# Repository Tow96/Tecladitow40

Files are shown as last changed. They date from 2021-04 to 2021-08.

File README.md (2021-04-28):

# Tecladitow-40





The Tecladitow40 is a simple 40% handwired ortholinear keyboard which utilizes 
[QMK](https://github.com/qmk/qmk_firmware) to communicate with any USB capable 
device. The Tecladitow40 is based on a Teensy2.0 microcontroller.

## Repository structure
The repository is divided in two subfolders, each containing a different part of 
the project. Further documentation can be found inside these folders.

1. [**Assembly**](/Assembly) - This folder contains the files that make up the 
physical keyboard. They are available in .SLDPRT and .STL formats.

2. [**Firmware**](/Firmware) - This folder contains the Hex file used to flash the
keyboard as well as a simple Test program to check the functionality of the keys.

## Future improvements
The specific improvements are separated by category inside the documentation for each folder.

- [ ] **Make rev1:** This revision will change the microcontroller to a pure 
ATmega32u4 and have a pcb.

## Credits
- Jose Tow [[@Tow96](https://github.com/Tow96)]

## License
This project is licensed under [GNU GPL-3.0](/LICENSE) as I believe in open source 
projects.

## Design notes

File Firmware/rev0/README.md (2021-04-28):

# Firmware
The tecladitow40 utilizes the QMK firmware. in this repository only the code to test the switches and the compiled hex file for the keyboard can be found.

The uncompiled version of the firmware can be found on this 
[forked repository](https://github.com/Tow96-forks/qmk_firmware).

## Future improvements
- [ ] Make rev1

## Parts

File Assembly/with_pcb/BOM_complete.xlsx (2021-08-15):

Item # | Part | Value | Qty | Description | Package | Type | LCSC-PART | Units per Lot | Lot Price (USD) | Total (1 brd) | Total (2 brd) | Total (3 brd) | Total (4 brd) | Total (5 brd) | Link
1 | C1-C47 | 0.1uF | 47 | Capacitor | 0402 | SMD | C392963 | 100 | 0.82 | 0.82 | 0.82 | 1.64 | 1.64 | 2.46 | https://es.aliexpress.com/item/32965092877.html
2 | C48, C51-C54 | 1uF | 5 | Capacitor | 0402 | SMD | C107372 | 100 | 0.82 | 0.82 | 0.82 | 0.82 | 0.82 | 0.82 | https://es.aliexpress.com/item/32965092877.html
3 | C49-C50 | 30pF | 2 | Capacitor | 0402 | SMD | C107004 | 100 | 0.82 | 0.82 | 0.82 | 0.82 | 0.82 | 0.82 | https://es.aliexpress.com/item/32965092877.html
4 | CR1-CR47 |  | 47 | SK6812Mini-E LED | - | SMD |  | 100 | 17.35 | 12.59 | 17.35 | 34.70 | 34.70 | 42.99 | https://es.aliexpress.com/item/4000475685852.html
5 | D1-D47 | 4148 | 47 | Diode | MINI-MELF | SMD | C402260 | 100 | 0.70 | 0.70 | 0.70 | 1.40 | 1.40 | 2.10 | https://es.aliexpress.com/item/1005002345510929.html
6 | G1 | 16MHz | 1 | 16MHz Crystal | SMD3225-4P | SMD | C12668 | 10 | 1.37 | 1.37 | 1.37 | 1.37 | 1.37 | 1.37 | https://es.aliexpress.com/item/1005002345332969.html
7 | J1 |  | 1 | Female USB-C | - | SMD | C393939 | 5 | 0.68 | 0.68 | 0.68 | 0.68 | 0.68 | 0.68 | https://lcsc.com/product-detail/USB-Connectors_SHOU-HAN-TYPE-C16PIN_C393939.html
8 | R1-R2 | 5.1K | 2 | Resistor | 0402 | SMD | C325521 | 100 | 0.64 | 0.64 | 0.64 | 0.64 | 0.64 | 0.64 | https://es.aliexpress.com/item/1005001793275257.html
9 | R3-R4 | 22 | 2 | Resistor | 0402 | SMD | C163821 | 100 | 0.64 | 0.64 | 0.64 | 0.64 | 0.64 | 0.64 | https://es.aliexpress.com/item/1005001793275257.html
10 | R5 | 10K | 1 | Resistor | 0402 | SMD | C140214 | 100 | 0.64 | 0.64 | 0.64 | 0.64 | 0.64 | 0.64 | https://es.aliexpress.com/item/1005001793275257.html
11 | R6 | 300 | 1 | Resistor | 0402 | SMD | C911734 | 100 | 0.64 | 0.64 | 0.64 | 0.64 | 0.64 | 0.64 | https://es.aliexpress.com/item/1005001793275257.html
12 | S1-S47 |  | 47 | Cherry MX Switch | CherryMX | thru-hole
13 | S48 |  | 1 | Tactile Switch | SMD,3*4 | SMD | C455280 | 100 | 1.76 | 1.76 | 1.76 | 1.76 | 1.76 | 1.76 | https://es.aliexpress.com/item/4001107238344.html
14 | U$1 |  | 1 | JST SR Female connector | - | SMD | C160407 | 10 | 2.04 | 2.04 | 2.04 | 2.04 | 2.04 | 2.04 | https://lcsc.com/product-detail/Wire-To-Board-Wire-To-Wire-Connector_JST-Sales-America-SM08B-SRSS-TB-LF-SN_C160407.html
15 | U1 |  | 1 | ATmega32u4MU | QFN-44_7x7x05P | SMD | C45874 | 5 | 29.10 | 29.10 | 29.10 | 29.10 | 29.10 | 29.10 | https://es.aliexpress.com/item/1005002509013804.html
16 | - | M2.5 | 5 | Screws | - | - | - | -
17 | - |  | 1 | 48 Ortholinear keycaps
 |  |  |  |  | Prices without discount nor shipment |  |  |  | SubTotal | 53.26 | 58.02 | 76.89 | 76.89 | 86.70
 |  |  |  |  |  |  |  |  | SubTotal per board | 53.2600 | 29.0100 | 25.6300 | 19.2225 | 17.3400
18 | - | - | 1 | PCB @ JLC | - | PCB | - | 5 | 60.5 | 60.50 | 60.50 | 60.50 | 60.50 | 60.50
 |  |  |  |  |  |  |  |  | Total | 113.76 | 118.52 | 137.39 | 137.39 | 147.20
 |  |  |  |  |  |  |  |  | Total per board | 113.7600 | 59.2600 | 45.7967 | 34.3475 | 29.4400

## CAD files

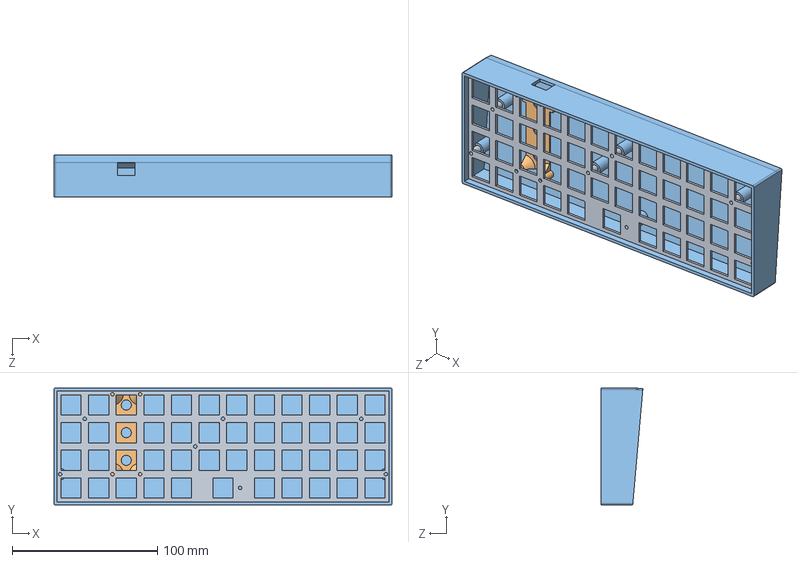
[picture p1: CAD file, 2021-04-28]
Assembly/hand-soldered/Keyboard.SLDASM
233.0 x 80.6 x 28.8 mm
01-Plate
02-TeensyBase
03-Body

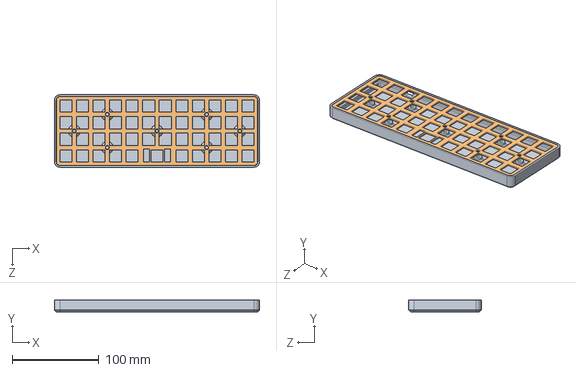
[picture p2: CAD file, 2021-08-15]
Assembly/with_pcb/Parts/_src/Assembly.SLDASM
235.8 x 13.5 x 83.4 mm
Plate

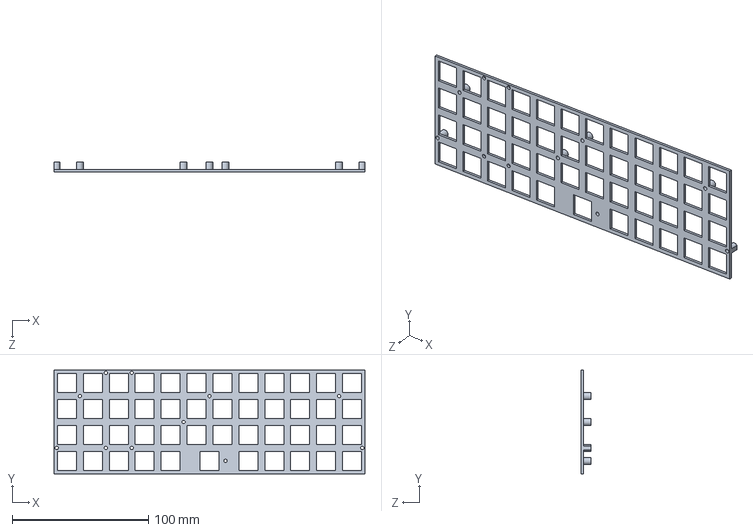
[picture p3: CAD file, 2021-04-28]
Assembly/hand-soldered/Parts/01-Plate.SLDPRT
228.6 x 76.2 x 7.20 mm

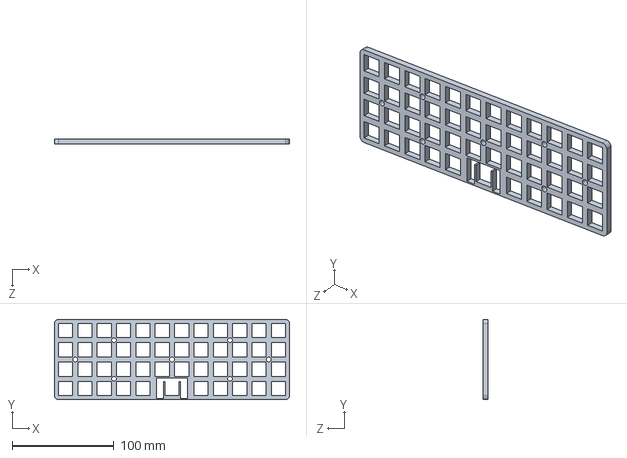
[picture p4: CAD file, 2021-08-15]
Assembly/with_pcb/Parts/_src/Plate.SLDPRT
231.4 x 79.0 x 5.00 mm

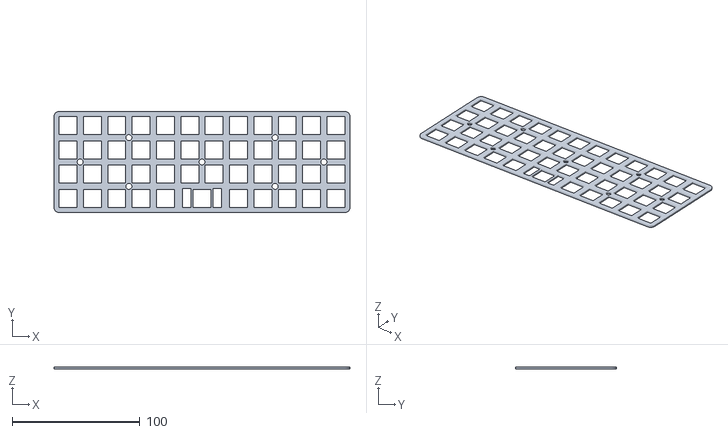
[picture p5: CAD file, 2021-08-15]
Assembly/with_pcb/Parts/STL/Plate_1.5mm.STL
231.4 x 79.0 x 1.50

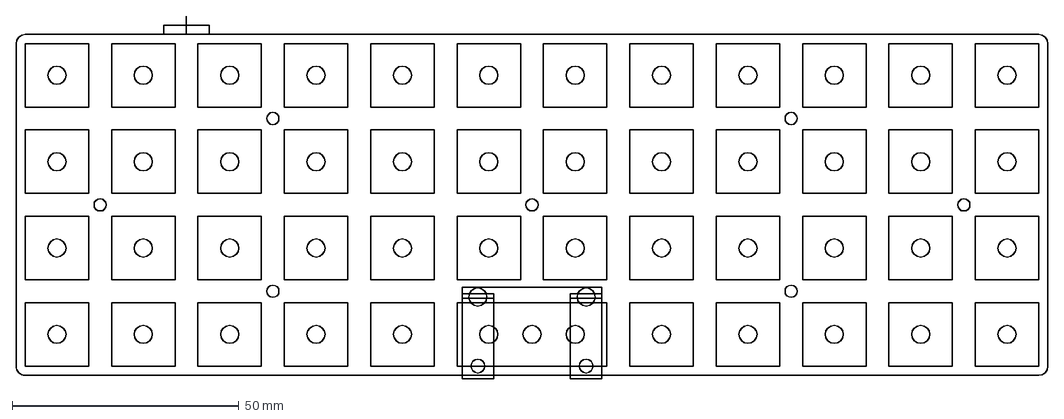
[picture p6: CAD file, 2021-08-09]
Assembly/with_pcb/reference_plate.dxf
227.5 x 79.9 mm

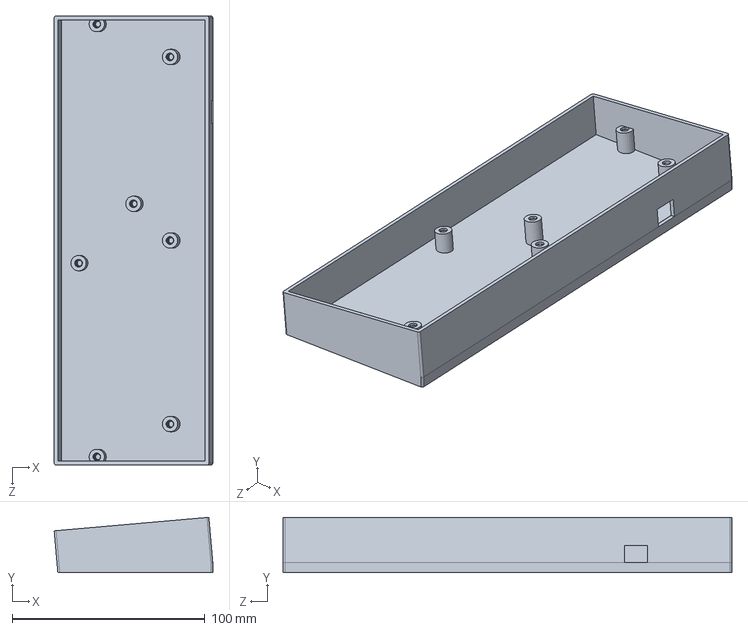
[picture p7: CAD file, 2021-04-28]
Assembly/hand-soldered/Parts/03-Body.SLDPRT
82.4 x 28.7 x 233.0 mm

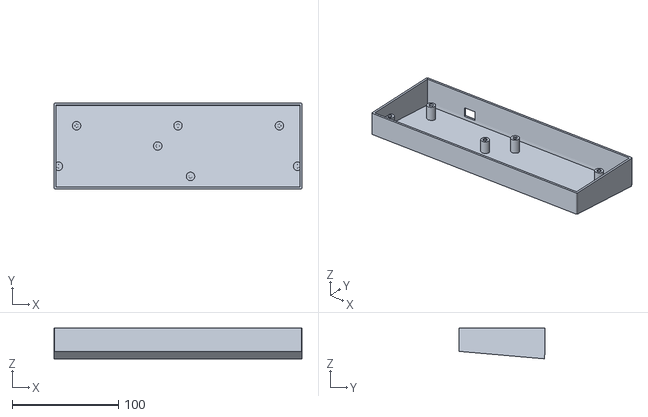
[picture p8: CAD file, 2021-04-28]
Assembly/hand-soldered/STL/Keyboard - 03-Body-1.STL
233.0 x 80.6 x 28.8

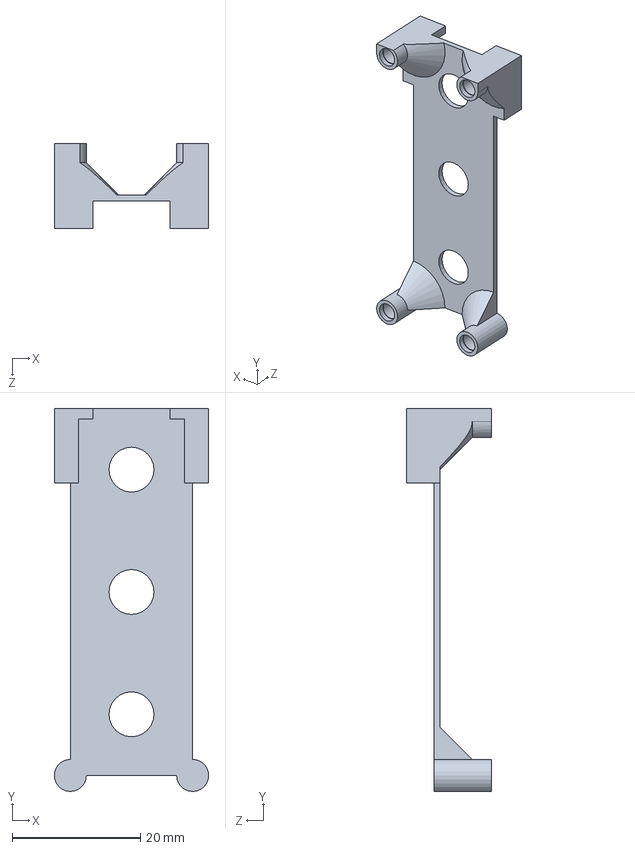
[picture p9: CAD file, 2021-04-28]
Assembly/hand-soldered/Parts/02-TeensyBase.SLDPRT
24.0 x 59.7 x 13.2 mm

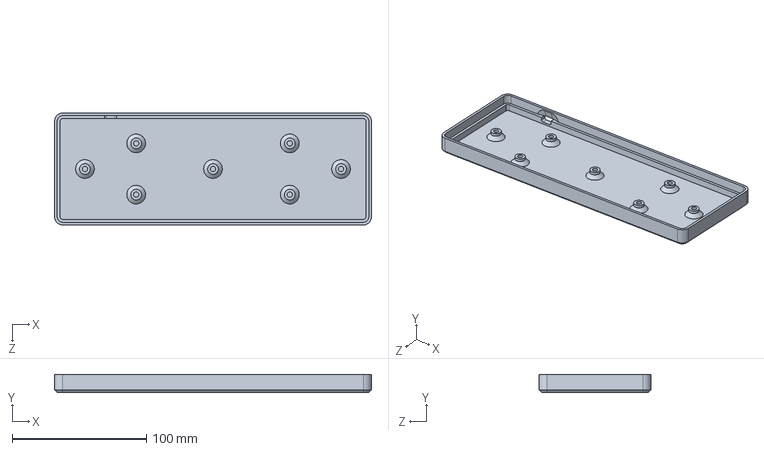
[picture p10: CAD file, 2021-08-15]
Assembly/with_pcb/Parts/_src/Body.SLDPRT
235.8 x 13.5 x 83.4 mm

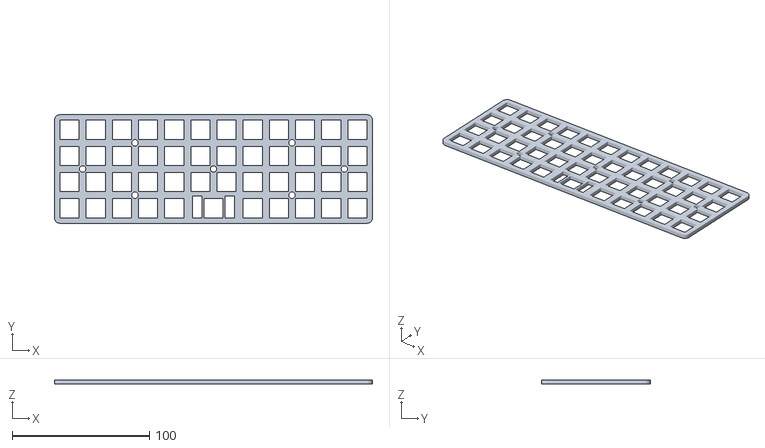
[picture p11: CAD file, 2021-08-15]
Assembly/with_pcb/Parts/STL/Plate_3.0mm.STL
231.4 x 79.0 x 3.00

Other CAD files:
Assembly/hand-soldered/STL/Keyboard - 01-Plate-1.STL
Assembly/with_pcb/Parts/STL/Plate_5.0mm.STL
Assembly/hand-soldered/STL/Keyboard - 02-TeensyBase-1.STL
Assembly/with_pcb/Parts/STL/Body.STL

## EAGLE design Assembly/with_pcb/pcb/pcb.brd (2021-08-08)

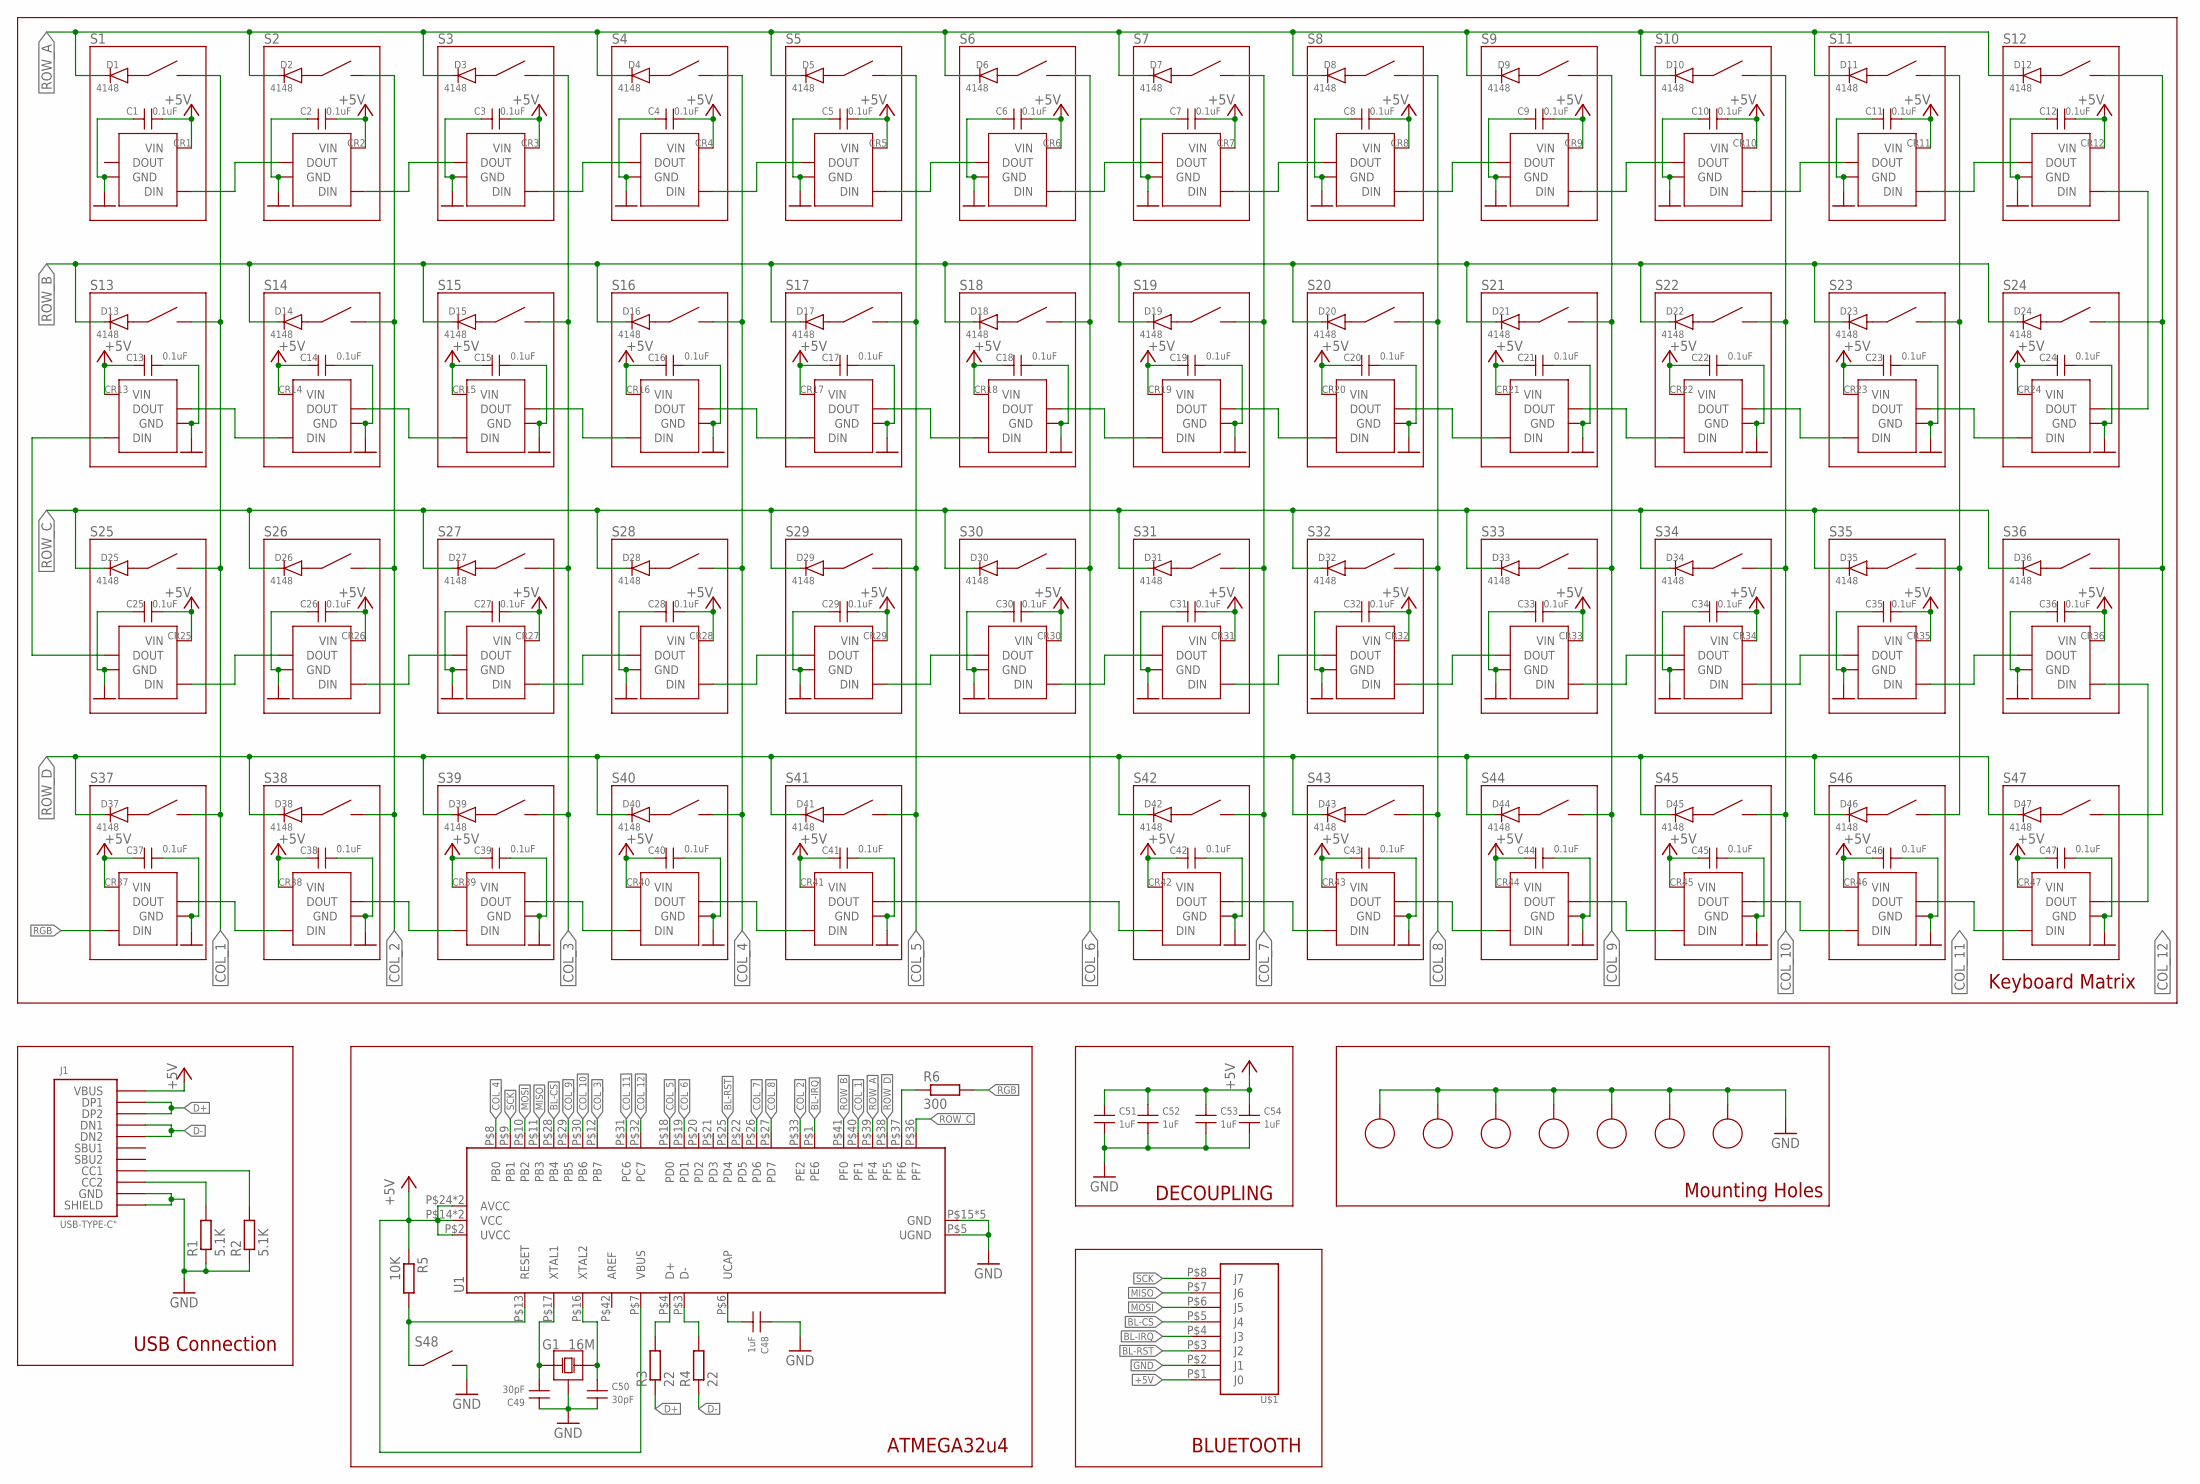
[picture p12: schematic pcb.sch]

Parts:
C1, C2, C3, C4, C5, C6, C7, C8, C9, C10, C11, C12, C13, C14, C15, C16, C17, C18, C19, C20, C21, C22, C23, C24, C25, C26, C27, C28, C29, C30, C31, C32, C33, C34, C35, C36, C37, C38, C39, C40, C41, C42, C43, C44, C45, C46, C47: 0.1uF; C0402
C48, C51, C52, C53, C54: 1uF; C0402
C49, C50: 30pF; C0402
CR1, CR2, CR3, CR4, CR5, CR6, CR7, CR8, CR9, CR10, CR11, CR12, CR13, CR14, CR15, CR16, CR17, CR18, CR19, CR20, CR21, CR22, CR23, CR24, CR25, CR26, CR27, CR28, CR29, CR30, CR31, CR32, CR33, CR34, CR35, CR36, CR37, CR38, CR39, CR40, CR41, CR42, CR43, CR44, CR45, CR46, CR47: SK6812MINI-E
D1, D2, D3, D4, D5, D6, D7, D8, D9, D10, D11, D12, D13, D14, D15, D16, D17, D18, D19, D20, D21, D22, D23, D24, D25, D26, D27, D28, D29, D30, D31, D32, D33, D34, D35, D36, D37, D38, D39, D40, D41, D42, D43, D44, D45, D46, D47: 4148; MINI_MELF
G1: 16M; SMD3225-4P
J1: USB-TYPE-C"; USB-C-SMD_TYPE-C16PIN
R1, R2: 5.1K; R0402
R3, R4: 22; R0402
R5: 10K; R0402
R6: 300; R0402
S1, S2, S3, S4, S5, S6, S7, S8, S9, S10, S11, S12, S13, S14, S15, S16, S17, S18, S19, S20, S21, S22, S23, S24, S25, S26, S27, S28, S29, S30, S31, S32, S33, S34, S35, S36, S37, S38, S39, S40, S41, S42, S43, S44, S45, S46, S47: MX_SWITCH
S48: SWITCH-SMD,3*4; SMD,3X4X2.0MM
U1: ATMEGA32U4-MUR; QFN-44_7X7X05P
U2, U3, U4, U5, U6, U7, U8: M2.5-HOLE; M2.5
U$1: JST-8PIN-SR; JST-SR-8PIN

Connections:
+5V: C1.P$2, C2.P$2, C3.P$2, C4.P$2, C5.P$2, C6.P$2, C7.P$2, C8.P$2, C9.P$2, C10.P$2, C11.P$2, C12.P$2, C13.P$1, C14.P$1, C15.P$1, C16.P$1, C17.P$1, C18.P$1, C19.P$1, C20.P$1, C21.P$1, C22.P$1, C23.P$1, C24.P$1, C25.P$2, C26.P$2, C27.P$2, C28.P$2, C29.P$2, C30.P$2, C31.P$2, C32.P$2, C33.P$2, C34.P$2, C35.P$2, C36.P$2, C37.P$1, C38.P$1, C39.P$1, C40.P$1, C41.P$1, C42.P$1, C43.P$1, C44.P$1, C45.P$1, C46.P$1, C47.P$1, C51.P$1, C52.P$1, C53.P$1, C54.P$1, CR1.P$1 (VIN), CR2.P$1 (VIN), CR3.P$1 (VIN), CR4.P$1 (VIN), CR5.P$1 (VIN), CR6.P$1 (VIN), CR7.P$1 (VIN), CR8.P$1 (VIN), CR9.P$1 (VIN), CR10.P$1 (VIN), CR11.P$1 (VIN), CR12.P$1 (VIN), CR13.P$1 (VIN), CR14.P$1 (VIN), CR15.P$1 (VIN), CR16.P$1 (VIN), CR17.P$1 (VIN), CR18.P$1 (VIN), CR19.P$1 (VIN), CR20.P$1 (VIN), CR21.P$1 (VIN), CR22.P$1 (VIN), CR23.P$1 (VIN), CR24.P$1 (VIN), CR25.P$1 (VIN), CR26.P$1 (VIN), CR27.P$1 (VIN), CR28.P$1 (VIN), CR29.P$1 (VIN), CR30.P$1 (VIN), CR31.P$1 (VIN), CR32.P$1 (VIN), CR33.P$1 (VIN), CR34.P$1 (VIN), CR35.P$1 (VIN), CR36.P$1 (VIN), CR37.P$1 (VIN), CR38.P$1 (VIN), CR39.P$1 (VIN), CR40.P$1 (VIN), CR41.P$1 (VIN), CR42.P$1 (VIN), CR43.P$1 (VIN), CR44.P$1 (VIN), CR45.P$1 (VIN), CR46.P$1 (VIN), CR47.P$1 (VIN), J1.A4B9 (VBUS), J1.B4A9 (VBUS), R5.P$1 (1), U1.P$2 (UVCC), U1.P$7 (VBUS), U1.P$14 (VCC), U1.P$24 (AVCC), U1.P$34 (VCC), U1.P$44 (AVCC), U$1.P$1 (J0)
BL-CS: U1.P$28 (PB4), U$1.P$5 (J4)
BL-IRQ: U1.P$1 (PE6), U$1.P$4 (J3)
BL-RST: U1.P$25 (PD4), U$1.P$3 (J2)
COL_1: S1.P$2, S13.P$2, S25.P$2, S37.P$2, U1.P$40 (PF1)
COL_2: S2.P$2, S14.P$2, S26.P$2, S38.P$2, U1.P$33 (PE2)
COL_3: S3.P$2, S15.P$2, S27.P$2, S39.P$2, U1.P$12 (PB7)
COL_4: S4.P$2, S16.P$2, S28.P$2, S40.P$2, U1.P$8 (PB0)
COL_5: S5.P$2, S17.P$2, S29.P$2, S41.P$2, U1.P$18 (PD0)
COL_6: S6.P$2, S18.P$2, S30.P$2, U1.P$19 (PD1)
COL_7: S7.P$2, S19.P$2, S31.P$2, S42.P$2, U1.P$26 (PD6)
COL_8: S8.P$2, S20.P$2, S32.P$2, S43.P$2, U1.P$27 (PD7)
COL_9: S9.P$2, S21.P$2, S33.P$2, S44.P$2, U1.P$29 (PB5)
COL_10: S10.P$2, S22.P$2, S34.P$2, S45.P$2, U1.P$30 (PB6)
COL_11: S11.P$2, S23.P$2, S35.P$2, S46.P$2, U1.P$31 (PC6)
COL_12: S12.P$2, S24.P$2, S36.P$2, S47.P$2, U1.P$32 (PC7)
D+: J1.A6 (DP1), J1.B6 (DP2), R3.P$1 (1)
D-: J1.A7 (DN1), J1.B7 (DN2), R4.P$1 (1)
GND: C1.P$1, C2.P$1, C3.P$1, C4.P$1, C5.P$1, C6.P$1, C7.P$1, C8.P$1, C9.P$1, C10.P$1, C11.P$1, C12.P$1, C13.P$2, C14.P$2, C15.P$2, C16.P$2, C17.P$2, C18.P$2, C19.P$2, C20.P$2, C21.P$2, C22.P$2, C23.P$2, C24.P$2, C25.P$1, C26.P$1, C27.P$1, C28.P$1, C29.P$1, C30.P$1, C31.P$1, C32.P$1, C33.P$1, C34.P$1, C35.P$1, C36.P$1, C37.P$2, C38.P$2, C39.P$2, C40.P$2, C41.P$2, C42.P$2, C43.P$2, C44.P$2, C45.P$2, C46.P$2, C47.P$2, C48.P$1, C49.P$1, C50.P$2, C51.P$2, C52.P$2, C53.P$2, C54.P$2, CR1.P$4 (GND), CR2.P$4 (GND), CR3.P$4 (GND), CR4.P$4 (GND), CR5.P$4 (GND), CR6.P$4 (GND), CR7.P$4 (GND), CR8.P$4 (GND), CR9.P$4 (GND), CR10.P$4 (GND), CR11.P$4 (GND), CR12.P$4 (GND), CR13.P$4 (GND), CR14.P$4 (GND), CR15.P$4 (GND), CR16.P$4 (GND), CR17.P$4 (GND), CR18.P$4 (GND), CR19.P$4 (GND), CR20.P$4 (GND), CR21.P$4 (GND), CR22.P$4 (GND), CR23.P$4 (GND), CR24.P$4 (GND), CR25.P$4 (GND), CR26.P$4 (GND), CR27.P$4 (GND), CR28.P$4 (GND), CR29.P$4 (GND), CR30.P$4 (GND), CR31.P$4 (GND), CR32.P$4 (GND), CR33.P$4 (GND), CR34.P$4 (GND), CR35.P$4 (GND), CR36.P$4 (GND), CR37.P$4 (GND), CR38.P$4 (GND), CR39.P$4 (GND), CR40.P$4 (GND), CR41.P$4 (GND), CR42.P$4 (GND), CR43.P$4 (GND), CR44.P$4 (GND), CR45.P$4 (GND), CR46.P$4 (GND), CR47.P$4 (GND), G1.P$2 (P2), G1.P$4 (P2), J1.A1B12 (GND), J1.B1A12 (GND), J1.SHIELD, J1.SHIELD1 (SHIELD), J1.SHIELD2 (SHIELD), J1.SHIELD3 (SHIELD), R1.P$1 (1), R2.P$1 (1), S48.P$2, U1.P$5 (UGND), U1.P$15 (GND), U1.P$23 (GND), U1.P$35 (GND), U1.P$43 (GND), U1.P$45 (GND), U2.P$1, U3.P$1, U4.P$1, U5.P$1, U6.P$1, U7.P$1, U8.P$1, U$1.P$2 (J1)
MISO: U1.P$11 (PB3), U$1.P$7 (J6)
MOSI: U1.P$10 (PB2), U$1.P$6 (J5)
unnamed: CR12.P$3 (DIN), CR24.P$2 (DOUT)
unnamed: CR13.P$3 (DIN), CR25.P$2 (DOUT)
unnamed: R3.P$2 (2), U1.P$4 (D+)
unnamed: J1.B5 (CC2), R1.P$2 (2)
unnamed: D1.P$2 (+), S1.P$1
unnamed: J1.A5 (CC1), R2.P$2 (2)
unnamed: R4.P$2 (2), U1.P$3 (D-)
unnamed: R5.P$2 (2), S48.P$1, U1.P$13 (RESET)
unnamed: CR1.P$3 (DIN), CR2.P$2 (DOUT)
unnamed: D2.P$2 (+), S2.P$1
unnamed: C48.P$2, U1.P$6 (UCAP)
unnamed: C49.P$2, G1.P$1 (P0), U1.P$17 (XTAL1)
unnamed: CR2.P$3 (DIN), CR3.P$2 (DOUT)
unnamed: D13.P$2 (+), S13.P$1
unnamed: R6.P$1 (1), U1.P$37 (PF6)
unnamed: CR13.P$2 (DOUT), CR14.P$3 (DIN)
unnamed: C50.P$1, G1.P$3 (P1), U1.P$16 (XTAL2)
unnamed: D20.P$2 (+), S20.P$1
unnamed: D3.P$2 (+), S3.P$1
unnamed: CR3.P$3 (DIN), CR4.P$2 (DOUT)
unnamed: CR19.P$2 (DOUT), CR20.P$3 (DIN)
unnamed: D14.P$2 (+), S14.P$1
unnamed: D4.P$2 (+), S4.P$1
unnamed: CR4.P$3 (DIN), CR5.P$2 (DOUT)
unnamed: CR14.P$2 (DOUT), CR15.P$3 (DIN)
unnamed: D5.P$2 (+), S5.P$1
unnamed: CR5.P$3 (DIN), CR6.P$2 (DOUT)
unnamed: D15.P$2 (+), S15.P$1
unnamed: CR15.P$2 (DOUT), CR16.P$3 (DIN)
unnamed: D6.P$2 (+), S6.P$1
unnamed: CR6.P$3 (DIN), CR7.P$2 (DOUT)
unnamed: D21.P$2 (+), S21.P$1
unnamed: CR20.P$2 (DOUT), CR21.P$3 (DIN)
unnamed: D7.P$2 (+), S7.P$1
unnamed: CR7.P$3 (DIN), CR8.P$2 (DOUT)
unnamed: D16.P$2 (+), S16.P$1
unnamed: CR27.P$3 (DIN), CR28.P$2 (DOUT)
unnamed: CR16.P$2 (DOUT), CR17.P$3 (DIN)
unnamed: D8.P$2 (+), S8.P$1
unnamed: CR8.P$3 (DIN), CR9.P$2 (DOUT)
unnamed: D17.P$2 (+), S17.P$1
unnamed: D9.P$2 (+), S9.P$1
unnamed: CR9.P$3 (DIN), CR10.P$2 (DOUT)
unnamed: CR17.P$2 (DOUT), CR18.P$3 (DIN)
unnamed: D22.P$2 (+), S22.P$1
unnamed: D10.P$2 (+), S10.P$1
unnamed: CR10.P$3 (DIN), CR11.P$2 (DOUT)
unnamed: CR21.P$2 (DOUT), CR22.P$3 (DIN)
unnamed: D18.P$2 (+), S18.P$1
unnamed: D11.P$2 (+), S11.P$1
unnamed: CR11.P$3 (DIN), CR12.P$2 (DOUT)
unnamed: D12.P$2 (+), S12.P$1
unnamed: D19.P$2 (+), S19.P$1
unnamed: CR18.P$2 (DOUT), CR19.P$3 (DIN)
unnamed: D23.P$2 (+), S23.P$1
unnamed: CR22.P$2 (DOUT), CR23.P$3 (DIN)
unnamed: D24.P$2 (+), S24.P$1
unnamed: CR23.P$2 (DOUT), CR24.P$3 (DIN)
unnamed: D25.P$2 (+), S25.P$1
unnamed: CR25.P$3 (DIN), CR26.P$2 (DOUT)
unnamed: D26.P$2 (+), S26.P$1
unnamed: CR26.P$3 (DIN), CR27.P$2 (DOUT)
unnamed: D27.P$2 (+), S27.P$1
unnamed: D28.P$2 (+), S28.P$1
unnamed: CR28.P$3 (DIN), CR29.P$2 (DOUT)
unnamed: D29.P$2 (+), S29.P$1
unnamed: CR29.P$3 (DIN), CR30.P$2 (DOUT)
unnamed: D30.P$2 (+), S30.P$1
unnamed: CR30.P$3 (DIN), CR31.P$2 (DOUT)
unnamed: D31.P$2 (+), S31.P$1
unnamed: CR31.P$3 (DIN), CR32.P$2 (DOUT)
unnamed: D32.P$2 (+), S32.P$1
unnamed: CR32.P$3 (DIN), CR33.P$2 (DOUT)
unnamed: D33.P$2 (+), S33.P$1
unnamed: CR33.P$3 (DIN), CR34.P$2 (DOUT)
unnamed: D34.P$2 (+), S34.P$1
unnamed: CR34.P$3 (DIN), CR35.P$2 (DOUT)
unnamed: D35.P$2 (+), S35.P$1
unnamed: CR35.P$3 (DIN), CR36.P$2 (DOUT)
unnamed: D36.P$2 (+), S36.P$1
unnamed: CR36.P$3 (DIN), CR47.P$2 (DOUT)
unnamed: D37.P$2 (+), S37.P$1
unnamed: D38.P$2 (+), S38.P$1
unnamed: CR37.P$2 (DOUT), CR38.P$3 (DIN)
unnamed: D39.P$2 (+), S39.P$1
unnamed: CR38.P$2 (DOUT), CR39.P$3 (DIN)
unnamed: D40.P$2 (+), S40.P$1
unnamed: CR39.P$2 (DOUT), CR40.P$3 (DIN)
unnamed: D41.P$2 (+), S41.P$1
unnamed: CR40.P$2 (DOUT), CR41.P$3 (DIN)
unnamed: D42.P$2 (+), S42.P$1
unnamed: CR41.P$2 (DOUT), CR42.P$3 (DIN)
unnamed: D43.P$2 (+), S43.P$1
unnamed: CR42.P$2 (DOUT), CR43.P$3 (DIN)
unnamed: D44.P$2 (+), S44.P$1
unnamed: CR43.P$2 (DOUT), CR44.P$3 (DIN)
unnamed: D45.P$2 (+), S45.P$1
unnamed: CR44.P$2 (DOUT), CR45.P$3 (DIN)
unnamed: D46.P$2 (+), S46.P$1
unnamed: CR45.P$2 (DOUT), CR46.P$3 (DIN)
unnamed: D47.P$2 (+), S47.P$1
unnamed: CR46.P$2 (DOUT), CR47.P$3 (DIN)
RGB: CR37.P$3 (DIN), R6.P$2 (2)
ROW_A: D1.P$1 (-), D2.P$1 (-), D3.P$1 (-), D4.P$1 (-), D5.P$1 (-), D6.P$1 (-), D7.P$1 (-), D8.P$1 (-), D9.P$1 (-), D10.P$1 (-), D11.P$1 (-), D12.P$1 (-), U1.P$39 (PF4)
ROW_B: D13.P$1 (-), D14.P$1 (-), D15.P$1 (-), D16.P$1 (-), D17.P$1 (-), D18.P$1 (-), D19.P$1 (-), D20.P$1 (-), D21.P$1 (-), D22.P$1 (-), D23.P$1 (-), D24.P$1 (-), U1.P$41 (PF0)
ROW_C: D25.P$1 (-), D26.P$1 (-), D27.P$1 (-), D28.P$1 (-), D29.P$1 (-), D30.P$1 (-), D31.P$1 (-), D32.P$1 (-), D33.P$1 (-), D34.P$1 (-), D35.P$1 (-), D36.P$1 (-), U1.P$36 (PF7)
ROW_D: D37.P$1 (-), D38.P$1 (-), D39.P$1 (-), D40.P$1 (-), D41.P$1 (-), D42.P$1 (-), D43.P$1 (-), D44.P$1 (-), D45.P$1 (-), D46.P$1 (-), D47.P$1 (-), U1.P$38 (PF5)
SCK: U1.P$9 (PB1), U$1.P$8 (J7)

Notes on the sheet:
Mounting Holes
Keyboard Matrix
USB Connection
ATMEGA32u4
DECOUPLING
BLUETOOTH

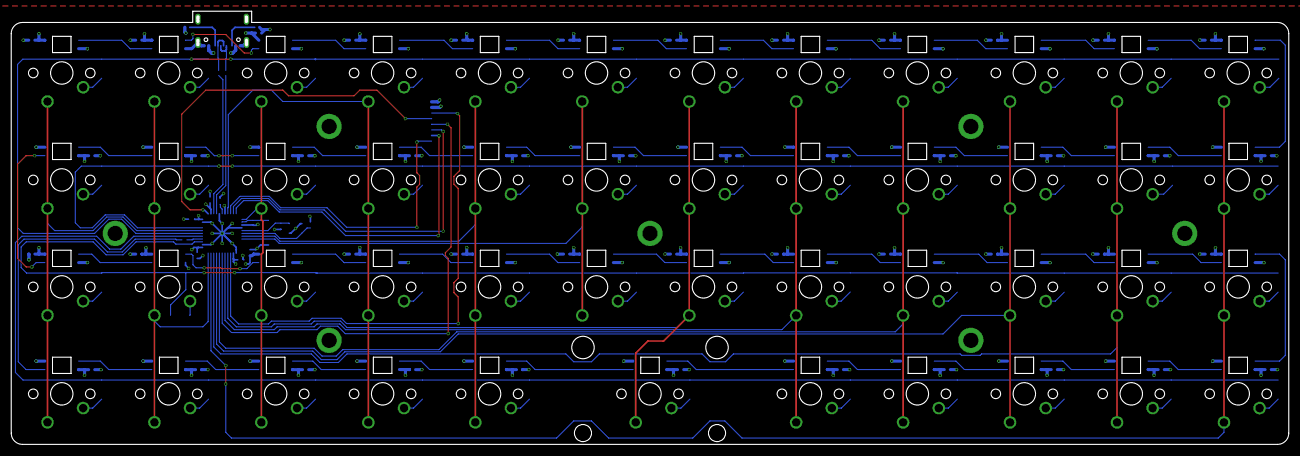
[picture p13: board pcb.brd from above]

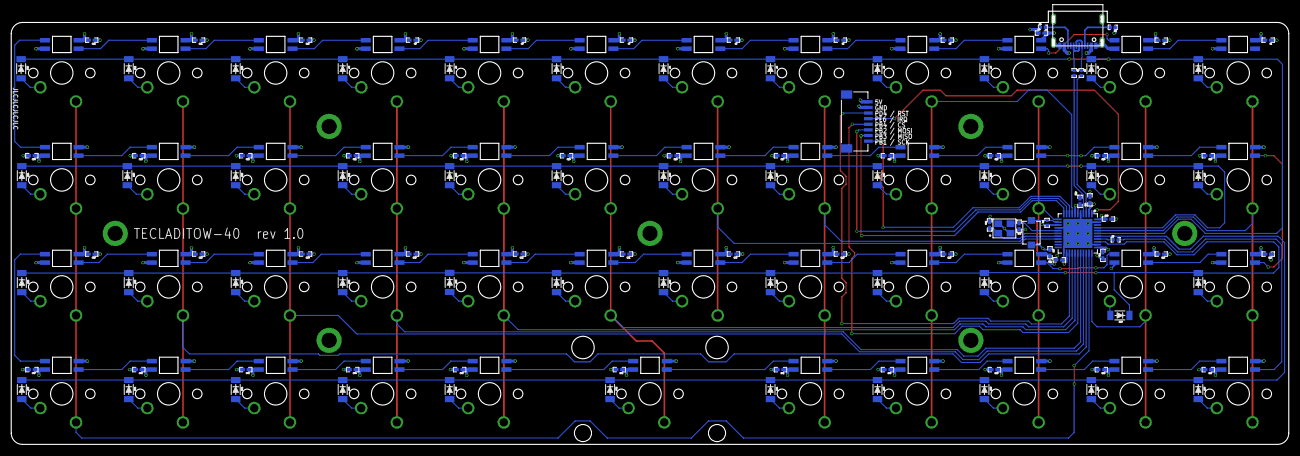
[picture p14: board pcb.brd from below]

Board: 4 copper layers, 227.5 x 77.2 mm, 213 parts (112 on the bottom side), 129 nets.

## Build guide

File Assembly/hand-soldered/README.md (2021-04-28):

# Assembly
This folder contains the files that make up the physical keyboard. They are 
available in .SLDPRT and .STL formats.

The files are:

- 01-Plate - Plate where all the switches are installed.

- 02-TeensyBase - Little jig to mount a Teensy2.0 without interfering with the 
wiring.

- 03-Body - Body of the Tecladitow40.

## Materials
The materials required to build the keyboard are the following:

Item                        | Qty
----------------------------| ---
Plate                       | 1
Teensybase                  | 1
Body                        | 1
M2.5x3x3.5 heat set inserts | 10
M2.5x10 screws              | 6
M2.5x5 screws               | 4
Cherry mx compatible switch | 47
1N4148 diodes               | 47
Ortholinear 40% keycaps set | 1
Teensy 2.0                  | 1
26 AWG Wire                 | ~1m

## Build instructions
- Print all the parts with either PLA or ABS with 10% infill, 5 top/bottom layers 
and layer a height of 0.2mm

- In order to simplify the wiring, open each cherry mx switch and install a diode 
inside with the marked side pointing to the right side of the switch looking it 
from above.

  - To open the switchs an opener tool can be downloaded from 
  [thingiverse](https://www.thingiverse.com/thing:2815698)

- Mount all the switches to the Plate.

- Flip the plate to see the underside. Then bend the right diode leg of each 
switch and solder it to the nearest pin.

- Bend all the legs of each diode in order to create 12 columns and solder them 
together.

  - Keep the legs as tense as possible as they will provide the keyboard's rigidity
  in the Y direction.

- Solder 4 26AWG wires to the switches to create the rows.

  - Keep these wires as tense as possible as they will provide the keyboard's 
  rigidity in the X direction.

  - On the top most row, avoid the TeensyBase mounting holes.

- Push 4 heat set inserts into the TeensyBase and screw it into the backside of 
the Plate using 4 M2.5x5 screws.

- Stick the Teensy 2.0 into the base with double sided tape.

- Solder each row and column to the following Teensy pins:

Part  | Pin
------| ---
RowA  | F5
RowB  | F6
RowC  | F7
RowD  | B6
Col1  | B5
Col2  | B4
Col3  | D7
Col4  | D6
Col5  | C7
Col6  | C6
Col7  | D3
Col8  | D2
Col9  | D1
Col10 | D0
Col11 | B7
Col12 | B3

- Flash the firmware to the Teensy2.0 Since it's the first time, the reset button 
on the Teensy must be pressed. More info can be found on the 
[Firmware](../Firmware/rev0) folder

- Push 6 heat set inserts into the Body piece.

- Place the keyboard assembly into the body and the screw it in place using 6 
M2.5x10 screws.

- Push every keycap onto its approppriate switch.

## Future improvements
- [ ] Make rev1

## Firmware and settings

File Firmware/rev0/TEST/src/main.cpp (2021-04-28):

#include <Arduino.h>
#include "../lib/buttons.h"
#include "pins.h"

Button buttonMatrix[48];

void setup()
{
  Serial.begin(9600);

  //pinMode(18, INPUT_PULLUP);
  //pinMode(14, OUTPUT);
  //digitalWrite(14, LOW);

  for (int i = 0; i < 4; i++)
  {
    pinMode(rowPins[i], INPUT_PULLUP);
  }

  for (int i = 0; i < 12; i++)
  {
    pinMode(colPins[i], OUTPUT);
    digitalWrite(colPins[i], HIGH);
  }
  
}

void loop()
{
  for (int i = 0; i < 12; i++)
  {
    digitalWrite(colPins[i], LOW);

    for (int j = 0; j < 4; j++)
    {
      int pos = (i*4) + j;
      buttonMatrix[pos].setState(!digitalRead(rowPins[j]));
    }

    digitalWrite(colPins[i], HIGH);
  }

  for (int i = 0; i < 48; i++)
  {
    int state = buttonMatrix[i].getState();

    if (state == BUTTON_RISINGEDGE) {
      Serial.print("Queue action set for key: ");
      Serial.println(i);
    }

  }
}

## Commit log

2021-04-28 Added rev0
    [01-Plate.SLDPRT, 02-TeensyBase.SLDPRT, 03-Body.SLDPRT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]
2021-08-08 Moved hand soldered elements (rev0) to it's own folder
    [01-Plate.SLDPRT, 02-TeensyBase.SLDPRT, 03-Body.SLDPRT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]
2021-08-08 Created eagle project for rev1
    [pcb.brd, pcb.sch]
2021-08-08 Gave more space for connection between ground plane and USB connection
    [pcb.brd]
2021-08-09 Added informational BOM
    This BOM is not intended for sending to a PCB manufacturer
    [BOM_complete.xlsx]
2021-08-09 Added the gerber files
    [BOM_tecladitow40-rev1.0.xlsx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]
2021-08-15 Made complete BOM
    [BOM_complete.xlsx]
2021-08-15 Created assembly parts
    [Assembly.SLDASM, Body.SLDPRT, Body.STL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]

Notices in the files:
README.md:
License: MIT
